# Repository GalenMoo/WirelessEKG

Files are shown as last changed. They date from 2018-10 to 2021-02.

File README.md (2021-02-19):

# WirelessEKG
Source Code for Wireless EKG

## Exterior
ClosedOtherSideAnnotated

ClosedSideAnnotated

## Interior
OpenedwoPCBAnnotated

Exploded View Annotated

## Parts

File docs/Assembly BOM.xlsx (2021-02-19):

Wireless EKG Assembly Bill of Materials
ITEM | REFERENCE DESIGNATOR | DESCRIPTION | SUGG. MFG. | SUGG. MFG-PN. | SUGG. DISTRIB. | SUGG. DIST. P.N. | LINK | QTY | PRICE
1 | N/A | 3D Printing Material PLA | Hatchbox | 3D PLA-1KG1.75-WHT | Amazon | B00J0GMMP6 | https://www.amazon.com/HATCHBOX-3D-Filament-Dimensional-Accuracy/dp/B00J0GMMP6?s=industrial | 1 | $19.99
2 | N/A | Disposable / Reusable Dry EEG Electrode | Flordia Research Instruments | TDE-200 | N/A | N/A | https://fri-fl-shop.com/product/tde-200/ | 1 ten pack | $10.00
3 | N/A | 30 AWG Flexible Silicone Wire Electric wire 30 gauge Coper Hook Up Wire 300V Cables electronic stranded wire cable electrics DIY BOX-1 | Striveday | N/A | Amazon | B01KQ2JNLI | https://www.amazon.com/StrivedayTM-Flexible-Silicone-electronic-electrics/dp/B01KQ2JNLI | 1 | $12.99
4 | N/A | Battery Packs Lithium Ion Polymer Battery 3.7V 1200mAh (1 piece) | Adafruit Industries LLC | 258 | Amazon | B00J2QET64 | https://www.amazon.com/gp/product/B00J2QET64/ref=ox_sc_sfl_title_1?ie=UTF8&psc=1&smid=AM0JQO74J587C | 1 | $15.35
5 | N/A | Adafruit Micro-Lipo Charger for LiPo/LiIon Batt w/MicroUSB Jack | Adafruit Industries LLC | ADA1904 | Amazon | B00MJ0HOKS | https://www.amazon.com/gp/product/B00MJ0HOKS/ref=od_aui_detailpages00?ie=UTF8&psc=1 | 1 | $8.04
6 | N/A | 8-32 0.312" Lg Brass Heat Set Insert for Plastic | McMaster Carr | 93365A142 | McMaster Carr | 93365A142 | https://www.mcmaster.com/#93365a142/=1ca5t76 | 1 | $8.62
7 | N/A | 8-32 7/16" Lg Steel Flat Head Phillips Screw | McMaster Carr | 90273A193 | McMaster Carr | 90273A193 | https://www.mcmaster.com/#90273a193/=1ca6nwr | 1 | $4.06
8 | N/A | 2-56 3/16" Nylon Pan Head Slotted Screws | McMaster Carr | 92942A706 | McMaster Carr | 92942A706 | https://www.mcmaster.com/92942A706 | 1 | $5.95
9 | N/A | 0.025" Thick Aluminum Sheet Metal | McMaster Carr | 89015K138 | McMaster Carr | 89015K138 | https://www.mcmaster.com/catalog/124/3768 | 1 | $17.60
10 | N/A | Rocker Switch SPST 10A (AC) 125V Panel Mount, Snap-In | ZF Electronics | SRB22A2FBBNN | Digikey | CH755-ND | https://www.digikey.com/product-detail/en/zf-electronics/SRB22A2FBBNN/CH755-ND/446021 | 1 | $0.95
11 | N/A | LED Panel Indicator Green, Red, Yellow 2.2V Green, 2V Red, 2.1V Yellow 20mA Round with Flat Top Solder Lug | APEM Inc. | Q8F8BZZRYG02E | Digikey | 679-4074-ND | https://www.digikey.com/products/en?keywords=Q8F8BZZRYG02E | 1 | $14.06
12 | N/A | Constructed PCB | See PCB BOM

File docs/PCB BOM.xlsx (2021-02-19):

Wireless EKG PCB Bill of Materials
ITEM | REFERENCE DESIGNATOR | DESCRIPTION | SUGG. MFG. | SUGG. MFG-PN. | SUGG. DISTRIB. | SUGG. DIST. P.N. | LINK | QTY | PRICE
1 | N/A | Fabricated Circuit Board | Bay Area Circuits | N/A | N/A | N/A | N/A | 1 | Price Vary
2 | U1 | IC REG LINEAR 1.8V 20MA SOT23-5 | Maxim Integrated | MAX1726EUK18+T | Digikey | MAX1726EUK18+T-ND | https://www.amazon.com/StrivedayTM-Flexible-Silicone-electronic-electrics/dp/B01KQ2JNLI | 1 | $1.95
3 | U2, U3, U4 | IC ECG FRONT END 28TQFN | Maxim Integrated | MAX30003CTI+ | Digikey | MAX30003CTI+-ND | https://www.digikey.com/product-detail/en/maxim-integrated/MAX30003CTI-/MAX30003CTI--ND/6226574 | 3 | $5.54
4 | J8 | CONN HEADER FEM 12POS.1" SGL TIN | Sullins Connector Solutions | PPTC121LFBN-RC | Digikey | S6100-ND | https://www.digikey.com/product-detail/en/sullins-connector-solutions/PPTC121LFBN-RC/S6100-ND/807231 | 1 | $0.78
5 | J9 | CONN HEADER FEMALE 16POS.1" TIN | Sullins Connector Solutions | PPTC161LFBN-RC | Digikey | S7014-ND | https://www.digikey.com/product-detail/en/sullins-connector-solutions/PPTC161LFBN-RC/S7014-ND/810154 | 1 | $0.98
6 | J10 | CONN HEADER FEMALE 4POS .1" TIN | Sullins Connector Solutions | PPTC041LFBN-RC | Digikey | S7002-ND | https://www.digikey.com/product-detail/en/sullins-connector-solutions/PPTC041LFBN-RC/S7002-ND/810144 | 1 | $0.45
7 | C1, C3, C4, C5 | CAP CER 10PF 1KV C0G/NP0 0805 | KEMET | C0805C100JDGACTU | Digikey | 399-7062-1-ND | https://www.digikey.com/product-detail/en/kemet/C0805C100JDGACTU/399-7062-1-ND/3439407 | 4 | $0.43
8 | C2, C6, C7, C10, C12, C15, C16, C19, C21, C24, C25, C28, C30 | CAP CER 1UF 10V X5R 0402 | Samsung Electro-Mechanics | CL05A105MP5NNNC | Digikey | 1276-1448-1-ND | https://www.digikey.com/product-detail/en/samsung-electro-mechanics/CL05A105MP5NNNC/1276-1448-1-ND/3889534 | 13 | $0.10
9 | C8, C17, C26 | CAP CER 0.1UF 10V X7R 0402 | TDK Corporation | C1005X7R1A104K050BB | Digikey | 445-4958-1-ND | https://www.digikey.com/product-detail/en/tdk-corporation/C1005X7R1A104K050BB/445-4958-1-ND/2093572 | 3 | $0.10
10 | C9, C11, C13, C18, C20, C22, C27, C29, C31 | CAP CER 10UF 6.3V X5R 0603 | Samsung Electro-Mechanics | CL10A106KQ8NNNC | Digikey | 1276-1038-1-ND | https://www.digikey.com/product-detail/en/samsung-electro-mechanics/CL10A106KQ8NNNC/1276-1038-1-ND/3889124 | 9 | $0.30
11 | C14, C23, C32 | CAP CER 1000PF 50V X7R 0402 | Murata Electronics North America | GRM155R71H102JA01D | Digikey | 490-6348-1-ND | https://www.digikey.com/product-detail/en/murata-electronics-north-america/GRM155R71H102JA01D/490-6348-1-ND/3845545 | 3 | $0.10
12 | R1, R6, R7, R10 | RES SMD 49.9K OHM 0.1% 1/8W 0805 | Panasonic Electronic Components | ERA-6AEB4992V | Digikey | P49.9KDACT-ND | https://www.digikey.com/product-detail/en/panasonic-electronic-components/ERA-6AEB4992V/P49.9KDACT-ND/3075162 | 4 | 0.36
13 | R2, R3, R4, R5, R8, R9, R11, R12 | RES SMD 0 OHM JUMPER 1/8W 0805 | Vishay Dale | CRCW08050000Z0EA | Digikey | 541-0.0ACT-ND | https://www.digikey.com/product-detail/en/vishay-dale/CRCW08050000Z0EA/541-0.0ACT-ND/1180267 | 8 | $0.10
14 | R13, R14, R15 | RES SMD 499K OHM 1% 1/10W 0603 | Panasonic Electronic Components | ERJ-3EKF4993V | Digikey | P499KHCT-ND | https://www.digikey.com/product-detail/en/panasonic-electronic-components/ERJ-3EKF4993V/P499KHCT-ND/198415 | 3 | $0.10
15 | R16 | RES SMD 10K OHM 0.5% 1/10W 0805 | Susumu | RR1220P-103-D | Digikey | RR12P10.0KDCT-ND | https://www.digikey.com/product-detail/en/susumu/RR1220P-103-D/RR12P10.0KDCT-ND/432854 | 1 | $0.11

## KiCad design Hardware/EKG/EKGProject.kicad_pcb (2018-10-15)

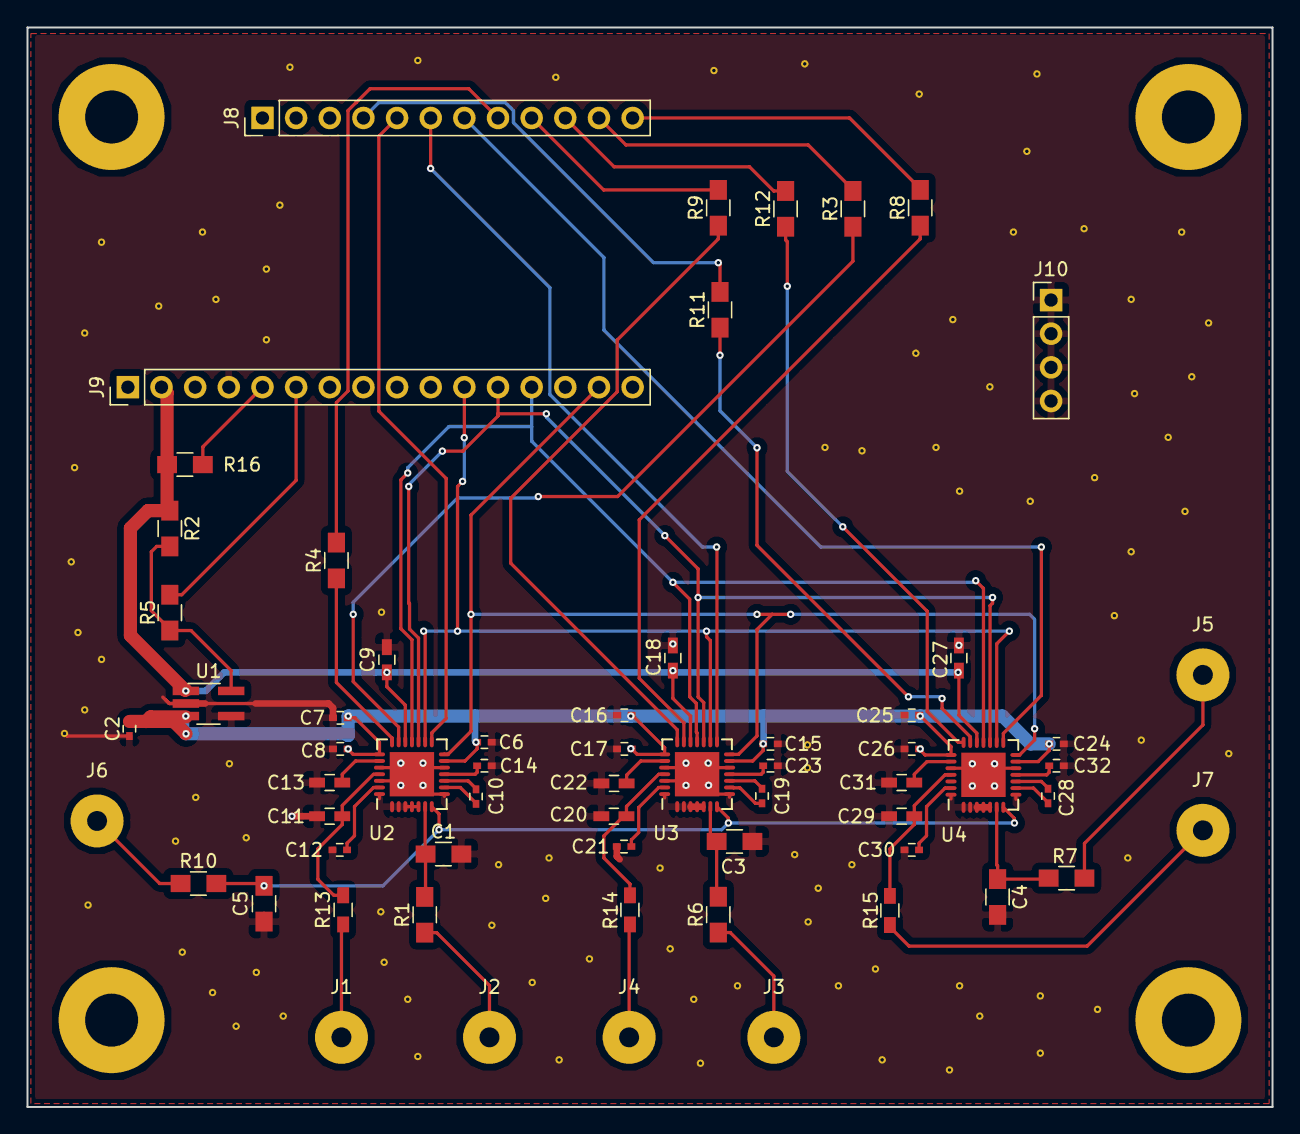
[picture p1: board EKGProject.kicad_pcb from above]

Board: 2 copper layers, 94.0 x 81.5 mm, 62 parts (0 on the bottom side), 54 nets.

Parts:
C1, C3, C4, C5: 10pF; R_0805_HandSoldering
C2, C6, C7, C10, C12, C15, C16, C19, C21, C24, C25, C28, C30: 1uF; C_0402
C8, C17, C26: 0.1uF; C_0402
C9, C11, C13, C18, C20, C22, C27, C29, C31: 10uF; C_0603_HandSoldering
C14, C23, C32: 1000pF; C_0402
J1, J2, J3, J5, J6: Screw_Terminal_01x01; SolderWirePad_single_1-5mmDrill
J4, J7: Conn_01x01; SolderWirePad_single_1-5mmDrill
J8: Conn_01x12; Pin_Header_Straight_1x12_Pitch2.54mm
J9: Conn_01x16; Pin_Header_Straight_1x16_Pitch2.54mm
J10: Conn_01x04; Pin_Header_Straight_1x04_Pitch2.54mm
R1, R6, R7, R10: 49.9k; R_0805_HandSoldering
R2, R3, R4, R5, R8, R9, R11, R12: 0; R_0805_HandSoldering
R13, R14, R15: 499k; R_0603_HandSoldering
R16: 10k; R_0805_HandSoldering
U1: MAX1726EUK18+; TSOT-23-5_HandSoldering
U2, U3, U4: MAX30003; QFN-28-1EP_5x5mm_Pitch0.5mm

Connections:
+1V8: C2.1, C6.1, C7.1, C8.1, C15.1, C16.1, C17.1, C24.1, C25.1, C26.1, U1.3, U2.13, U2.22, U3.13, U3.22, U4.13, U4.22
+3V3: C9.1, C18.1, C27.1, J9.2, R2.1, R16.1, U1.1, U2.19, U3.19, U4.19
/CS_1: J8.5, U2.15
/CS_2: J8.6, U3.15
/CS_3: J8.7, U4.15
/ECGN: J6.1, R10.1
/ECGN_R: C5.1, R10.2, U2.7, U3.7, U4.7
/ECGP_1: J2.1, R1.1
/ECGP_1_R: C1.1, R1.2, U2.6
/ECGP_2: J3.1, R6.1
/ECGP_2_R: C3.1, R6.2, U3.6
/ECGP_3: J5.1, R7.1
/ECGP_3_R: C4.1, R7.2, U4.6
/EKG_1/CAPN: C10.2, U2.10
/EKG_1/CAPP: C10.1, U2.9
/EKG_1/PLL: C14.1, U2.11
/EKG_1/VBG: C12.1, U2.27
/EKG_1/VCM_R: C11.1, R13.2, U2.25
/EKG_1/VREF: C13.1, U2.23
/EKG_2/CAPN: C19.2, U3.10
/EKG_2/CAPP: C19.1, U3.9
/EKG_2/PLL: C23.1, U3.11
/EKG_2/VBG: C21.1, U3.27
/EKG_2/VCM_R: C20.1, R14.2, U3.25
/EKG_2/VREF: C22.1, U3.23
/EKG_3/CAPN: C28.2, U4.10
/EKG_3/CAPP: C28.1, U4.9
/EKG_3/PLL: C32.1, U4.11
/EKG_3/VBG: C30.1, U4.27
/EKG_3/VCM_R: C29.1, R15.2, U4.25
/EKG_3/VREF: C31.1, U4.23
/FCLK: J9.15, U2.14, U3.14, U4.14
/GPIO_14: J9.5, R16.2
/INT2B_1: J8.11, R3.2
/INT2B_1_R: R3.1, U2.20
/INT2B_2: J8.12, R8.2
/INT2B_2_R: R8.1, U3.20
/INT2B_3: J8.4, R11.2
/INT2B_3_R: R11.1, U4.20
/INTB_1: J8.8, R4.2
/INTB_1_R: R4.1, U2.21
/INTB_2: J8.9, R9.2
/INTB_2_R: R9.1, U3.21
/INTB_3: J8.10, R12.2
/INTB_3_R: R12.1, U4.21
/MISO: J9.13, U2.18, U3.18, U4.18
/MOSI: J9.12, U2.17, U3.17, U4.17
/SCLK: J9.11, U2.16, U3.16, U4.16
/SHDN_L: J9.6, R5.1
/SHDN_L_R: R2.2, R5.2, U1.5
/VCM_1: J1.1, R13.1
/VCM_2: J4.1, R14.1
/VCM_3: J7.1, R15.1
Earth: C1.2, C2.2, C3.2, C4.2, C5.2, C6.2, C7.2, C8.2, C9.2, C11.2, C12.2, C13.2, C14.2, C15.2, C16.2, C17.2, C18.2, C20.2, C21.2, C22.2, C23.2, C24.2, C25.2, C26.2, C27.2, C29.2, C30.2, C31.2, C32.2, J9.4, J10.1, J10.2, J10.3, J10.4, U1.2, U1.4, U2.1, U2.2, U2.3, U2.4, U2.5, U2.8, U2.12, U2.24, U2.26, U2.28, U2.29, U3.1, U3.2, U3.3, U3.4, U3.5, U3.8, U3.12, U3.24, U3.26, U3.28, U3.29, U4.1, U4.2, U4.3, U4.4, U4.5, U4.8, U4.12, U4.24, U4.26, U4.28, U4.29

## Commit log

2018-05-03 Added Hardware folder containing schematic and parts
    [EKG.sch, EKGProject.kicad_pcb, EKGProject.sch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]
2018-05-10 Add files via upload
    Updated schematic
    Final version V1
    [EKG.sch, EKGProject.sch]
2018-05-30 Recent route 5/29
    [EKG.sch, EKGProject.dsn, EKGProject.sch]
2018-09-09 Added excel sheets
    [BOM.xlsx]
2018-09-24 updated super close finished layout
    [EKGProject.kicad_pcb]
2018-09-27 hopefully final board layout?
    [EKGProject.kicad_pcb]
2018-10-08 final final final hopefully
    [BOM.xlsx, EKG.sch, EKGProject.dsn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]
2018-10-08 DFM quick check
    [EKGProject.kicad_pcb]
2018-10-08 DFM changes again
    [EKGProject.kicad_pcb]
2018-10-08 one more time DFM lets goooo
    [EKGProject.kicad_pcb]
2018-10-08 final minus ground vias
    [EKGProject.kicad_pcb]
2018-10-10 add ground stiching
    [EKGProject.kicad_pcb]
2018-10-15 upload footprint library
2018-10-15 deleted master
    [BOM.xlsx, EKG.sch, EKGProject.dsn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]
2018-10-15 last adjustments
    [EKGProject.kicad_pcb]
2018-10-15 Final Revisions
    [BOM.csv, BOM.xlsx, EKGProject.kicad_pcb]
2018-10-15 last BOM update
    [BOM.csv]
2021-02-19 updated boms
    [Assembly BOM.xlsx, BOM.csv, PCB BOM.xlsx]
